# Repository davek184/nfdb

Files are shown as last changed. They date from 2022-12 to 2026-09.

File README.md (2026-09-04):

# USB-C Daughterboard for Norbaforce 

For all models of the Norbaforce (also works with the Norbauer Data Pad). 

Features USB-C port, ESD protection, over voltage protection, CC1 & CC2 resistors to work with USB-C to C cables.  

Finishes on Norbaforces vary greatly.  They were designed for USB mini cables so it is possible a USB-C cable end may not fit depending a finish. In those cases a very light filing of the USB opening using a hobby file can enlarge the opening just enough for the cable.

_(Note there is one PCB that can have a connector for Realforce 1 OR Realforce 2 models)_

# Version No Keyboard Connector
RenderNoConnector
<br><br><br>

# Version Realforce R1 
  RenderRF1
* **Models:** 86U, 87U, 88U, 91U
* **PCB Connector:** LCSC: C265068
* **Cable:** EH to EH (2.5mm pitch), 4 pin, SAME direction, Length 6cm (shielding cable 13cm)

RF1Pinnout
<br><br><br>

# Version Realforce R2 
  RenderRF2
* **Models:** R2 TKL, R2 RGB TKL, RT1 (numpad)
* **PCB Connector:** LCSC: C69152
* **Cable:** PH to PH (2.0mm pitch), 5 pin, REVERSED Direction, Length 11cm

RF2Pinnout
<br><br>

# Manufacturing
<details>
  <summary>Details</summary>
* Manufacturing files are set up for JLCPCB. 
* Thickness does not matter suggest standard 1.6mm 
* "Remove Order Number" option choose "Specify Location" (uses "JLCJLC" on silkscreen for order # position)
* Assemble top side
* Choose assembly file version (No connector: need to solder then yourself, RF1 or RF2 as indicated above in renders)
* Manual part adjustments from KiCad Outputs (already handled in manufacturing files)

| Part | Adjustment |
| --- | --- |
| USB-C Connector | Down 5.06mm |
| JST EH Connector  | Up 3.75mm |
| JST PH  Connector | Rotate 90°, Down 4mm |

## BOM

| LCSC part # | Description | Value | Package  | Amount |
| --- | --- | ----- | --- | --- |
| C261942 | Fuse | | 0805 | 1 |
| C7519 | ESD | | SOT23-6  | 1 |
| C212411 | Resistor | 5.1K  | 0805 | 2 |
| C597300 | Capacitor | 4.7nF | 0805 | 1 |
| C165948 | Connector (USB)  | | TH | 1 |
| C265068 | Connector (EH) | 4 pin | TH | 1 |
| C69152 | Connector (PH) | 5 pin | TH | 1 |

_Note if the capacitor or resistors are out of stock they can be replaced with 0805 sized component with similar specs._
</details>

# EH -> PH Cable Experiments
<details>
  <summary>Details</summary>
Tested a sample cable using manufactured PH crimped wires in an EH cable housing end (LCSC: C161661) to make a PH to EH cable without manually crimping.  Worked without issues after 350 connection cycles.  Potential could use R2 daughterboard connector can be used for both R2 and R1 boards.

CableEHToPH
</details>

# Notes
<details>
  <summary>R2 NFDB and the Realforce RT1 (Topre numpad)</summary>

The R2 NFDB is compatible with the Topre Realforce RT1 numpad (released in 2024), which shares a similar footprint to the predecessor Realforce 23u.  
RT12

</details>  
<details>
  <summary>Photos</summary>

Norbaforce MKI (cutout is USB shape no issues with fit)
NFMKI
Norbaforce MKIII (unfinished no fit issues)
NFMKII
Norbaforce MKII RF2
NFMKiib
Norbaforce MKII (slight internal filing was needed)
NFMKIIInside
Norbauer Data Pad and the R1 NFDB
DataPad
Norbauer Data Pad with RT1 pcb - use R2 NFDB
RT1
</details>

# Special thanks 
* Nekotato: for requesting, testing & driving this project
* Techbeezin: for test fitting the vast collection of Norbaforces 
* Cipulot: answering various questions regarding Realforce and general electrical questions/advice
* d0nk: for pre-testing the R2 OEM cabling/pinout on RT1

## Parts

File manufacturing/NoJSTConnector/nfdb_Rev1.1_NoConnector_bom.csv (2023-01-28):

Designator | Footprint | Quantity | Value | LCSC Part #
C1 | R_0805 | 1 | 4.7n | C597300
F1 | F_0805 | 1 | Polyfuse_Small | C261942
J1 | HRO-TYPE-C-31-M-12 | 1 | TYPE-C-31-M-12 | C165948
R1, R2 | R_0805 | 2 | 5.1k | C212411
U1 | USBLC6-2SC6 | 1 | USBLC6-2SC6 | C7519

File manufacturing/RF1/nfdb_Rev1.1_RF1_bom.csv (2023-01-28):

Designator | Footprint | Quantity | Value | LCSC Part #
C1 | R_0805 | 1 | 4.7n | C597300
F1 | F_0805 | 1 | Polyfuse_Small | C261942
J1 | HRO-TYPE-C-31-M-12 | 1 | TYPE-C-31-M-12 | C165948
J2 | JST_EH_S4B-EH_1x04_P2.50mm_Horizontal | 1 | JST_EH_S4B-EH_1x04_P2.50mm_Horizontal | C265068
R1, R2 | R_0805 | 2 | 5.1k | C212411
U1 | USBLC6-2SC6 | 1 | USBLC6-2SC6 | C7519

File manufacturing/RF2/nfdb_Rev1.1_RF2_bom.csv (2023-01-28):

Designator | Footprint | Quantity | Value | LCSC Part #
C1 | R_0805 | 1 | 4.7n | C597300
F1 | F_0805 | 1 | Polyfuse_Small | C261942
J1 | HRO-TYPE-C-31-M-12 | 1 | TYPE-C-31-M-12 | C165948
J3 | JST_PH_S5B-PH-K_1x05_P2.00mm_Horizontal | 1 | JST_PH_S5B-PH-K_1x05_P2.00mm_Horizontal | C69152
R1, R2 | R_0805 | 2 | 5.1k | C212411
U1 | USBLC6-2SC6 | 1 | USBLC6-2SC6 | C7519

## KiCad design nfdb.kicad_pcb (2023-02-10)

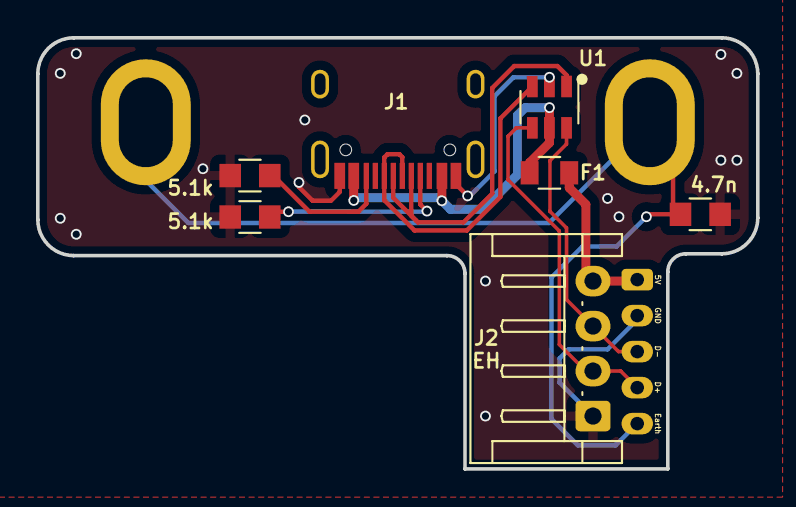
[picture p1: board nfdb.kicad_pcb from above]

Board: 2 copper layers, 40.0 x 24.0 mm, 8 parts (0 on the bottom side), 9 nets.

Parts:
C1: 4.7n; R_0805
F1: Polyfuse_Small; F_0805
J1: TYPE-C-31-M-12; HRO-TYPE-C-31-M-12
J2: JST_EH_S4B-EH_1x04_P2.50mm_Horizontal
J3: JST_PH_S5B-PH-K_1x05_P2.00mm_Horizontal
R1, R2: 5.1k; R_0805
U1: USBLC6-2SC6

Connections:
D+: J2.2, J3.4, U1.4 (I/O2)
D-: J2.3, J3.3, U1.6 (I/O1)
Earth: C1.2, J3.5
GND: C1.1, J1.1 (GND), J1.12 (GND), J2.1, J3.2, R1.2, R2.2, U1.2 (GND)
unnamed: J1.4 (CC1), R1.1
unnamed: J1.5 (DN2), J1.7 (DN1), U1.1 (I/O1)
unnamed: J1.6 (DP1), J1.8 (DP2), U1.3 (I/O2)
unnamed: J1.10 (CC2), R2.1
VBUS: F1.1, F1.2, J1.2 (VBUS), J1.11 (VBUS), J2.4, J3.1, U1.5 (VBUS)

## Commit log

2022-12-31 MKi & MKii seperation to different files
    [nfdb.kicad_pcb, nfdb.kicad_sch, nfdb_mki.kicad_pcb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]
2023-01-06 rev 1.1
    [nfdb.kicad_pcb, nfdb_mkii.kicad_pcb, nfdb_mkii.kicad_sch]
2023-01-21 Fixed mkii R2 ground traces
    [nfdb_mkii.kicad_pcb]
2023-01-23 Rev 1.3 unified design (use different cable for RF1 vs RF2
    Rev 1.3 unified design (use different cable for RF1 vs RF2
    [nfdb_mkii-B_Cu.gbr, nfdb_mkii-B_Fab.gbr, nfdb_mkii-B_Mask.gbr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]
2023-01-28 Went back to 1 db design to rule them all
    [nfdb.kicad_pcb, nfdb.kicad_sch, nfdb_Rev1.1_NoConnector_bom.csv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]
2023-02-10 Silk Screen Adjustment
    [nfdb.kicad_pcb]
2023-02-22 Rev 1.3
    Small Silkscreen adjustment
